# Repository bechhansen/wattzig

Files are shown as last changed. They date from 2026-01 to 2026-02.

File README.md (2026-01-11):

# WattZig - The Open Zigbee Power Meter









A Zigbee-based smart power meter reader for ESP32C6 that reads 3-phase electrical data via DLMS protocol and reports measurements to Zigbee hubs (Home Assistant, etc.).

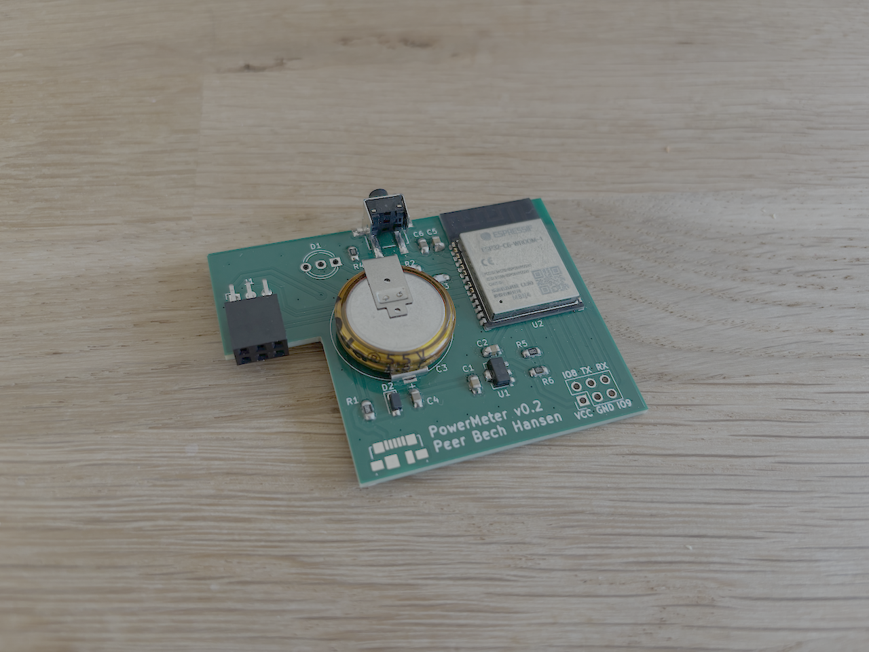
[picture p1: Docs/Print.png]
WattZig Hardware


## Overview

WattZig reads meter data via DLMS protocol over UART and reports 3-phase electrical measurements (voltage, current, active/reactive power, power factor, energy counters) through ZHA-compliant Zigbee clusters.

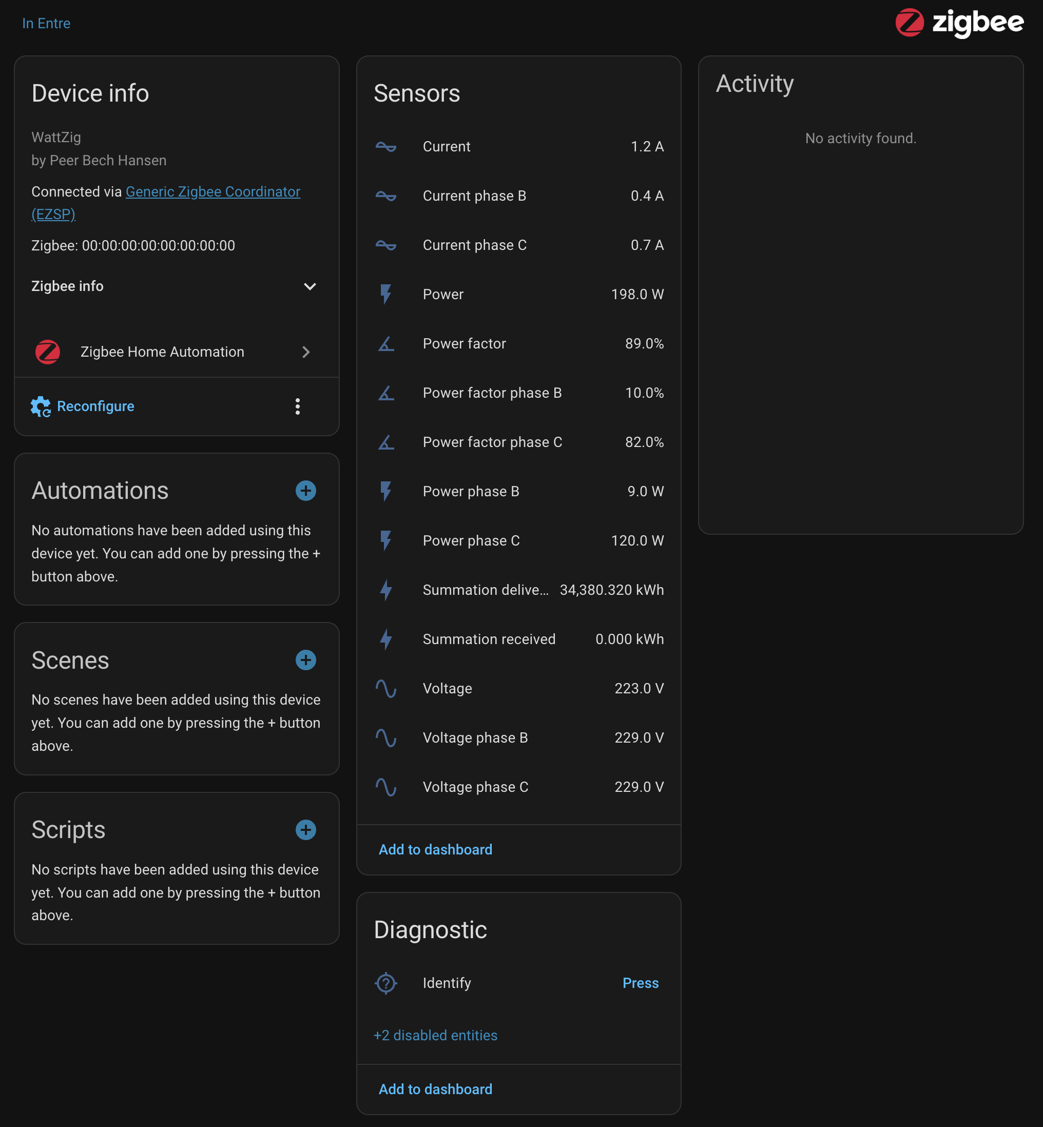
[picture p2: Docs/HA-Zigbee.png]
Zigbee Home Automation Interface


*The WattZig device reporting real-time electrical measurements to Home Assistant via Zigbee. All three phases show voltage (~228-230V), current (0.0-0.7A), power (9.0-130W), and power factor (11%-86%). The device also reports total energy consumption (34,351.77 kWh delivered) and can be integrated into automations and dashboards.*

## Features

- **3-Phase Metering**: Voltage, current, active/reactive power, power factor (phases A, B, C)
- **Energy Tracking**: Import/export energy counters with reporting
- **Zigbee ZHA**: Home Assistant integration via standard clusters
- **DLMS Parser**: State machine-based protocol handler at 2400 baud
- **Low Power**: FreeRTOS task design with Zigbee sleep support
- **Auto-Commissioning**: Network steering on first start
- **Status LEDs**: Green (data transmission), Red (commissioning)
- **Button Controls**: Long press (4s) = factory reset, double-click = restart

## Hardware Requirements

- **Microcontroller**: ESP32C6 (required for Zigbee)
- **ESP-IDF**: v5.5.2 (exact version)
- **Power Supply**: ≥4.5V input, MCP1700-3302E 3.3V regulator, 470µF–1000µF bulk capacitor (parallel to regulator)
- **UART1** (DLMS): TX=GPIO0, RX=GPIO1, 2400 baud, 8 bits, no parity
- **Peripherals**: GPIO5=Red LED, GPIO6=Green LED, GPIO4=Button

See [HARDWARE.md](HARDWARE.md) for complete Bill of Materials, schematics, and assembly instructions.

## Software Requirements

- **ESP-IDF v5.5.2**: `git clone -b v5.5.2 https://github.com/espressif/esp-idf.git && ./install.sh && source export.sh`
- **Dependencies** (auto-installed):
  - `espressif/esp-zigbee-lib` (~1.6.8)
  - `espressif/esp-zboss-lib` (~1.6.4)
  - `espressif/button` (2.4.1)

## Installation & Setup

1. **Clone and configure:**
   ```bash
   git clone <repo-url>
   cd wattzig/Software
   idf.py menuconfig
   ```

2. **Required menuconfig settings:**
   - `Component Config > Zigbee > Enable Zigbee Stack`
   - `Component Config > Zigbee > Device Type > End Device`
   - `Component Config > Power Management > Enable Power Management`

3. **Build and flash:**
   ```bash
   idf.py build
   idf.py -p /dev/ttyUSB0 -b 115200 flash
   idf.py -p /dev/ttyUSB0 monitor  # Exit: Ctrl+T then X
   ```

   See [FLASHING.md](FLASHING.md) for detailed hardware setup, boot mode configuration, and troubleshooting.

## Usage

**First Start:**
1. Device boots and performs factory reset
2. LED blinks (commissioning mode)
3. Device joins nearest Zigbee network via network steering
4. LED on briefly, then off
5. UART task starts reading meter data

**Normal Operation:**
- Device loads saved network config
- UART reads DLMS frames from meter
- Parsed data updates Zigbee cluster attributes
- Energy counters trigger ZCL reports

**Zigbee Endpoint 10:**
- Basic Cluster (0x0000): Device info
- Identify Cluster (0x0003): Identification
- Electrical Measurement (0x0B04): Voltage, current, power, power factor (all phases)
- Metering Cluster (0x0702): Energy delivered/received

## Configuration

Edit [Software/main/main.h](Software/main/main.h) for:
```c
#define ENDPOINT_ID 10                    // Zigbee endpoint
#define UART_NUM UART_NUM_1               // UART peripheral
#define UART_BAUD_RATE 2400               // Meter communication speed
#define LED_PIN 5                         // Red status LED
#define LED_PIN2 6                        // Green status LED
#define ED_AGING_TIMEOUT ESP_ZB_ED_AGING_TIMEOUT_64MIN
#define ED_KEEP_ALIVE 3000                // Keep-alive interval (ms)
```

## Debugging

### Enable Debug Logging
```c
// In app_main(), modify:
esp_log_level_set("Parser", ESP_LOG_DEBUG);  // Enable DLMS parser logs
esp_log_level_set("*", ESP_LOG_INFO);         // General logs
```

## References

- [ESP-IDF v5.5.2 Documentation](https://docs.espressif.com/projects/esp-idf/en/v5.5.2/)
- [Zigbee Cluster Library (ZCL)](https://zigbeealliance.org/)
- [Zigbee Cluster Library Specification](https://zigbeealliance.org/wp-content/uploads/2019/12/07-5123-06-zigbee-cluster-library-specification.pdf)
- [DLMS/COSEM Protocol](https://www.dlms.com/)
- [Home Assistant ZHA Integration](https://www.home-assistant.io/integrations/zha/)

## License

This project is licensed under the **GNU General Public License v3 (GPLv3)**.

You are free to use, modify, and distribute this software under the following conditions:
- Any derivative works must also be released under GPLv3
- You must provide access to the source code
- You must include this license and attribution
- You cannot create proprietary closed-source versions

See [LICENSE](LICENSE) for full details.

**GPLv3 ensures that improvements and modifications remain open source for the entire community.**

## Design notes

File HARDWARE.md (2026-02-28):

# WattZig Hardware - Bill of Materials (BOM)

## Summary
Complete electronic component list for WattZig ESP32C6-based Zigbee power meter reader.

## Microcontroller

| Qty | Part | Description | Notes | Ref |
|-----|---|---|---|-----|
| 1 | **ESP32-C6-WROOM-1** | 32-bit microcontroller with Zigbee/BLE | 2.4 GHz wireless, 160 MHz | U2 |

## Power Supply

| Qty | Part | Value | Package | Notes | Ref |
|-----|---|---|---|---|-----|
| 1 | **MCP1700-3302E** | 3.3V, 150mA LDO regulator | SOT-23-3 | Low dropout, stable 3.3V output | U1 |
| 1 | **Electrolytic Capacitor** | 470µF–1000µF, 6.3V+ | Through-hole or SMD | Prevents brownout| C? |
| 1 | **PHV-5R4H155-R** (PHV-5R4H474-R)| 1.5F, 5.4V | Through-hole | Supercapacitor for supplying suffiecent power to circuit | C3 |
| 2 | **Ceramic Capacitor** | 100nF (0.1µF) | 0603 SMD | Bypass capacitors (near VCC pins) |  |
| 1 | **Ceramic Capacitor** | 10µF | 0603 SMD | Additional smoothing |  |
| 1 | **1N5817W** | 450 mV @ 1 A | SOD-123 | Schottky Barrier Diode | D2 |

## I/O & Connectors

| Qty | Part | Description | Interface | Notes | Ref |
|-----|---|---|---|---|-----|
| 1 | **PPTC032LJBN-RC** | DLMS meter connection | 6POS (2X3) 2.54mm | https://www.digikey.at/en/products/detail/sullins-connector-solutions/PPTC032LJBN-RC/775975| J2 |
| 1 | **Programming Header** |  | 6-pin | For bootloader flashing | J1 |

## Status Indicators

| Qty | Part | Color | Package | GPIO | Function | Ref |
|-----|---|---|---|---|---|-----|
| 1 | **LED** | Red/Green |  | GPIO5 | Status indicator - commissioning | D1 |
| 2 | **Current Limiting Resistor** | 220Ω–330Ω | 1/4W or 0603 SMD | — | LED series resistors | |

## Control Interface

| Qty | Part | Type | Package | GPIO | Function | Url | Ref |
|-----|---|---|---|---|---|-----|-----|
| 1 | **Push Button** | Tactile switch, 12mm | 4-pin THT or SMD | GPIO4 | Long press (4s) = factory reset, double-click = restart | https://www.digikey.dk/da/products/detail/cit-relay-and-switch/CS1102V5-85F100/16607637 | SW1 |
| 1 | **Pull-up Resistor** | 10kΩ | 1/4W or 0603 SMD | — | Button debouncing |  | 

## Optional: Voltage Monitoring (Commented Code - WIP)

| Qty | Part | Value | Package | Notes | Ref |
|-----|---|---|---|---|-----|
| 2 | **Resistor** | 10kΩ | 1/4W or 0603 SMD | Voltage divider for VCC monitoring (ADC) |  |

### UART Pinout (Meter Connection)
```
Pin 1: GND
Pin 2: TX (GPIO0) - from ESP32 to meter (output)
Pin 3: RX (GPIO1) - from meter to ESP32 (input)
```
Baud rate: 2400, 8 bits, no parity, 1 stop bit

### GPIO Restrictions During Programming
- **GPIO8**: Must be HIGH during flash
- **GPIO9**: Must be LOW during flash
- These pins are not used in firmware

### LED Circuit
```
GPIO5 (Red LED)   ---|[220Ω]---|>|-----|GND
GPIO6 (Green LED) ---|[220Ω]---|>|-----|GND
```

### Button Circuit
```
GPIO4 ---|[10kΩ pull-up]---VCC
       |
       └──[Button]──GND
```

## Power Specifications

| Parameter | Value | Notes | Ref |
|---|---|---|-----|
| **Input voltage** | 4.5V–5.5V DC | Minimum 4.5V for regulator dropout | — |
| **Recommended input** | 5V @ 500mA minimum | Power supply capability | — |
| **Regulated output** | 3.3V @ 150mA | LDO regulator limit | U2 |
| **ESP32-C6 current** | ~80mA (active), ~20µA (sleep) | Idle load much lower | U1 |
| **Sleep mode** | ~10–50µA | With Zigbee sleep enabled | — |

## Supplier References (Example)

| Component | Example Part # | Supplier | Notes | Ref |
|---|---|---|---|-----|
| ESP32-C6-WROOM-1 | ESP32-C6-WROOM-1 | Digi-Key, Mouser | Check stock/lead times | U1 |
| MCP1700-3302E | MCP1700-3302E/CB | Digi-Key, Mouser | SOT-23 package | U2 |
| Bulk Capacitor | EKMG160ELL471MK20S | Digi-Key (Panasonic) | 470µF 10V electrolytic | C1 |
| LED Red | LTST-C150R | Digi-Key (Lite-On) | 3mm through-hole | LED1 |
| LED Green | LTST-C150G | Digi-Key (Lite-On) | 3mm through-hole | LED2 |
| Push Button | 9453 (Omron) | Digi-Key | 12mm tactile switch | SW1 |

## Revision History

| Version | Date | Changes |
|---|---|---|
| v10 | 2026-01-18 | Added Ref column to all BOM tables for component tracking |
| v9 | 2025-10-01 | Fixed supercapacitor placement (parallel, not series); confirmed bulk capacitor requirement |
| v8 | 2025-07-21 | Button moved to GPIO4; UART pins confirmed GPIO0/1 |
| v7 | 2025-06-10 | MCP1700-3302E selected; power circuit redesign |

## Cost Estimate (USD)

| Category | Est. Cost | Notes | Ref |
|---|---|---|-----|
| ESP32-C6-WROOM-1 | $3–5 | Module (prices vary by volume) | U1 |
| Regulator + Caps | $1–2 | MCP1700 + bulk cap + ceramics | U2, C1–C5 |
| LEDs + Resistors | $0.50 | Basic components | LED1, LED2, R1, R2 |
| Button + Resistor | $0.50 | Tactile switch | SW1, R3 |
| PCB | $2–5 | Prototype (Jlcpcb, Oshpark) | PCB1 |
| Connectors | $1–2 | JST headers, UART connector | J1–J3 |
| Enclosure | $1–3 | 3D printed resin or SLS | — |
| **Total** | **~$10–20** | Prototype quantities (1–10 units) | — |

## Next Steps for Assembly

1. Order PCB from Gerber files in `PCB/Out v0.1/`
2. Procure components from BOM above
3. Reflow solder (if SMD) or hand-solder THT components
4. **Critical check**: Verify bulk capacitor is parallel to regulator
5. Power test: Apply 5V, check 3.3V output with multimeter
6. Program ESP32-C6 via SPI/JTAG or UART bootloader
7. Assemble into 3D-printed enclosure (`3DPrint/WattZig v9.3mf`)

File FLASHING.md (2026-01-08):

# Firmware Upload Guide

This guide describes how to upload firmware to the PowerMeter ESP32C6 hardware using the service connector and standard flashing tools.

## Hardware Setup

### Service Connector Pinout

The PowerMeter hardware features a 6-pin service connector (2.54mm pitch) for programming and debugging:

| Pin | Signal | Purpose |
|-----|---|---|
| 1 | GND | Ground |
| 2 | VCC 3.3V | 3.3V Power Supply |
| 3 | TX | UART TX (GPIO1) |
| 4 | RX | UART RX (GPIO0) |
| 5 | GPIO8 | Boot Mode Control (High for Bootloader) |
| 6 | GPIO9 | Boot Mode Control (Low for Bootloader) |

### Required Hardware

1. **USB to UART Serial Adapter**: CP2102 STC or similar FTDI-based module
   - Must support 3.3V logic levels
   - Provides USB connectivity for flashing

2. **Test Rack PCB Clip**: 2.54mm pitch 6-pin clip connector
   - Connects to the service connector on the PowerMeter PCB
   - Allows quick connect/disconnect without soldering

3. **Cables**: Standard USB cable and connecting wires (typically included with serial adapter)

### Connection Diagram

Connect the USB to UART adapter to the service connector:

```
USB Adapter          Service Connector
───────────          ─────────────────
GND          ────→   GND (Pin 1)
5V/3.3V      ────→   VCC 3.3V (Pin 2)
TX (out)     ────→   RX (Pin 4)
RX (in)      ←────   TX (Pin 3)
GPIO/DTR/etc ────→   GPIO8 (Pin 5) - via pull-up or direct
GPIO/RTS/etc ────→   GPIO9 (Pin 6) - via pull-up or direct
```

**Important**: Ensure the USB adapter operates at 3.3V logic levels. Do not connect 5V directly to GPIO pins.

## Boot Mode Selection

To upload firmware, the ESP32C6 must be placed in bootloader mode.

### Boot Mode Requirements

For the ESP32C6 to enter bootloader mode:
- **GPIO8**: Must be pulled **HIGH** (typically connected to VCC 3.3V)
- **GPIO9**: Must be pulled **LOW** (typically connected to GND)

### Manual Boot Mode Entry

1. **Power off** the device
2. **Connect GPIO8 to VCC 3.3V** (high)
3. **Connect GPIO9 to GND** (low)
4. **Power on** the device
5. Device enters bootloader mode and is ready for flashing
6. After successful flashing, normal operation resumes automatically

###

## Flashing Firmware

### Prerequisites

1. Install esptool:
   ```bash
   pip install esptool
   ```

2. Confirm serial port availability:
   - **Linux/macOS**: `/dev/ttyUSB0` or `/dev/ttyUSB1` (or check with `ls /dev/tty*`)
   - **Windows**: `COM3`, `COM4`, etc. (check Device Manager)

### Standard Flashing Procedure

The standard way to flash firmware using esptool is:

#### Step 1: Download Firmware Binaries

Download the latest PowerMeter firmware release from GitHub:

1. Go to the [PowerMeter Releases](../../releases) page
2. Download the single release zip (e.g., `powermeter-v1.0.0-alpha.1.zip`) which contains:
   - `bootloader.bin` (bootloader)
   - `partition-table.bin` (partition table)
   - `firmware.bin` (application firmware)
3. Extract the zip to a local directory (e.g., `~/Downloads/powermeter-firmware/`)

#### Step 2: Put Device in Bootloader Mode

Manually connect GPIO8 (high) and GPIO9 (low) as described in [Boot Mode Selection](#boot-mode-selection).

#### Step 3: Flash Firmware

From the directory containing the downloaded .bin files:

```bash
esptool.py --chip esp32c6  --before default_reset --after hard_reset write_flash \
   --flash_size 4MB \
   0x0 bootloader.bin \
   0x8000 partition-table.bin \
   0x10000 firmware.bin

```

## Troubleshooting

### Device Not Found

- Confirm USB adapter is connected and recognized: `esptool.py version`
- Check port name: `esptool.py chip_id` (will list available ports)
- On Linux/macOS: May require `sudo` or udev rule configuration

### Connection Timeout During Flash

- Verify GPIO8 and GPIO9 are correctly set for bootloader mode
- Ensure 3.3V power is supplied during flashing
- Try lower baud rate: `-b 115200` instead of 460800

### CRC Error or Invalid Image

- Verify all three .bin files exist and are uncorrupted (check file sizes are reasonable, typically >100KB)
- Ensure you're in the correct directory containing bootloader.bin, partition-table.bin, and PowerMeter.bin
- Verify correct flash offsets: 0x0 (bootloader), 0x8000 (partition table), 0x20000 (application)
- Try erasing flash first (warning: clears all data):
  ```bash
  esptool.py -p /dev/ttyUSB0 erase_flash
  esptool.py -p /dev/ttyUSB0 -b 460800 --before default_reset --after hard_reset write_flash \
    --flash_mode dio --flash_freq 80m --flash_size keep \
    0x0 bootloader.bin 0x8000 partition-table.bin 0x20000 PowerMeter.bin
  ```

### Port Permission Denied (Linux)

Add user to dialout group:

```bash
sudo usermod -a -G dialout $USER
sudo reboot
```

Then unplug/replug USB adapter.

## Next Steps

After successful flashing:

1. Device boots automatically
2. LED blinks (commissioning mode)
3. Device joins the nearest Zigbee network
4. See [README.md](README.md) for normal operation details

## Building Firmware from Source

If you want to build firmware from source code instead of using pre-built binaries:

1. Clone the repository and navigate to `PowerMeter/Software`
2. Install [ESP-IDF v5.5.2](https://docs.espressif.com/projects/esp-idf/en/v5.5.2/esp32c6/get-started/index.html)
3. Run `idf.py menuconfig` to configure build options
4. Build with `idf.py build`
5. Flash using the steps above, replacing `bootloader.bin`, `partition-table.bin`, and `PowerMeter.bin` with paths in `build/bootloader/`, `build/partition_table/`, and `build/` respectively

## References

- [esptool.py Documentation](https://github.com/espressif/esptool)
- [Espressif Boot Mode Selection](https://docs.espressif.com/projects/esptool/en/latest/esp32c6/advanced-topics/boot-mode-selection.html)
- [ESP32C6 Datasheet](https://www.espressif.com/sites/default/files/documentation/esp32-c6_datasheet_en.pdf)

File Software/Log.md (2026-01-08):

2025-10-01
Code is running. For some reason it restarted because of brownout.
Monitoring only works just after flash. Maybe we need to set speed.

We need a bulk capacitor to prevent brownout

When searching for parts, look for:

"Electrolytic capacitor" - this is the capacitor type
Values: 470µF, 1000µF, or anywhere in between
Voltage rating: at least 6.3V (10V or 16V is common and fine)
Through-hole or SMD depending on your board

2025-07-21
When programming, GPIO8 needs to be high. GPIO9 needs to be low.
As we do not use GPIO8 for anything else we should be able to just set it to high.

Moved button pin from 7 to 4. It now works
TX and RX to 0 and 1. 

Programming works. Remember to disable logs.

Dual LED diode behaving strangely.

2025-06-10  
Found out my power circuit is wrong. I had the supercapacitor connected in series and not in parallel to the voltage regulator.
Also, the voltage regulator I'm using needs 4.5V because of a slight voltage drop. I need to use an MCP1700-3302E.

Use 10kΩ + 10kΩ voltage divider to read VCC voltage

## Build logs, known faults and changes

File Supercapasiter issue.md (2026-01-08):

# ESP32-C6 Zigbee Power Supply Issue - Documentation Summary

## Issue Description
ESP32-C6 brownout resets during Zigbee network initialization due to inadequate power delivery from supercapacitor with excessive ESR (Equivalent Series Resistance).

## Root Cause Analysis

### Current Hardware Configuration
- **Supercapacitor**: CE5R5105HF-ZJ (CDA Cap CE Series)
  - Capacitance: 1.0F
  - Voltage Rating: 5.5V
  - **ESR: 30Ω** ← PRIMARY PROBLEM
  - Height: 6.0mm
  - **Status**: Previously shorted, likely damaged (ESR may be higher than 30Ω)

- **Power Supply**: USB limited to 45mA average
- **LDO Regulator**: MCP1700T-3302E/MB (250mA max, 3.3V output)
- **Supply Voltage**: 4.1V at LDO input
- **Decoupling Network**: 470µF electrolytic (2cm from ESP32) + 10µF + 100nF ceramics

### Power Requirements
- **Zigbee TX Burst**: 100-150mA for milliseconds
- **Normal Operation**: ~30-50mA
- **Light Sleep**: ~1mA
- **Data Interval**: Every 10 seconds via UART

### Why 30Ω ESR Fails

**Voltage Drop Calculation:**
```
At 150mA Zigbee TX:
Voltage drop = 150mA × 30Ω = 4.5V

Available voltage = 4.1V - 4.5V = NEGATIVE (complete voltage collapse)
```

Even at 100mA:
```
Voltage drop = 100mA × 30Ω = 3.0V
Available voltage = 4.1V - 3.0V = 1.1V (insufficient for 3.3V LDO regulation)
```

The LDO requires minimum ~3.6V input to maintain 3.3V output. With 30Ω ESR, the voltage collapses below this threshold during Zigbee transmission, causing brownout resets.

## Solution Requirements

### Supercapacitor Specifications Needed
- **ESR**: <5Ω (preferably <3.5Ω)
- **Capacitance**: ≥0.47F (1.0F preferred)
- **Voltage Rating**: ≥5.5V
- **Height**: ≤10mm (ideally ≤13mm if flexibility possible)
- **Status**: Undamaged (never shorted)

### Recommended Supercapacitor Options

#### Option 1: KEMET FT Series (BEST PERFORMANCE)
**Part Number**: FT0H105ZF
- Capacitance: 1.0F
- **ESR: 3.5Ω** ✓ (8.5× better than current)
- Voltage: 5.5V
- Height: **13.0mm** (3mm over target)
- Max Current (30 min): 1.5mA

**Voltage drop at 150mA**: 150mA × 3.5Ω = **525mV** (acceptable)
**Available voltage**: 4.1V - 0.525V = **3.575V** ✓ (sufficient for LDO)

**Trade-off**: Exceeds height constraint by 3mm but provides excellent performance.

#### Option 2: Alternative Search Required
No supercapacitors found that meet BOTH <10mm height AND <5Ω ESR requirements. This is a fundamental physics limitation - low ESR requires larger electrode surface area.

### Alternative Power Solutions

#### LiPo Battery (RECOMMENDED IF HEIGHT CRITICAL)
- **Voltage**: 3.7V, 150-250mAh
- **ESR**: <0.1Ω (35× better than FT0H105ZF, 300× better than current)
- **Thickness**: 4-6mm ✓
- **Requires**: Charge management IC (e.g., MCP73831)
- **Advantages**: 
  - Ideal for pulse current applications
  - Fits height constraint
  - Much lower ESR
  - Designed for exactly this use case

## Working Solution: Light Sleep Mode

### Implementation Strategy
Given 10-second data intervals, implement light sleep with UART wake-up:
```c
// Power consumption in light sleep: ~1mA
// Voltage drop: 1mA × 30Ω = 30mV (acceptable)
// Recharge time: 9.9 seconds per cycle (sufficient)

esp_sleep_enable_uart_wakeup(UART_NUM);
esp_light_sleep_start();
```

### Additional Optimizations Required

1. **Reduce Zigbee TX Power**
```c
   esp_zb_set_tx_power(0);  // 0 dBm instead of maximum
   // Further reduction: -3 dBm or -6 dBm if range permits
```

2. **Lower CPU Frequency**
```c
   esp_pm_config_t pm_config = {
       .max_freq_mhz = 80,  // Reduce from 160MHz
       .min_freq_mhz = 40,
       .light_sleep_enable = true
   };
```

3. **Move 470µF Bulk Capacitor Closer**
   - **Current**: 2cm from ESP32-C6
   - **Target**: <5mm from ESP32-C6 power pins
   - Reduces trace inductance and resistance

4. **Verify Decoupling Network Integrity**
   - 470µF electrolytic on 3.3V rail
   - 10µF ceramic at ESP32-C6
   - 100nF ceramic at ESP32-C6 power pins (<5mm)

## Critical Issue: Zigbee Pairing

### Pairing Power Requirements
- **Duration**: 10-30+ seconds continuous
- **Current**: 80-150mA sustained (not just bursts)
- **Total Energy**: ~10 Watt-seconds

### Why Current Supercap CANNOT Handle Pairing
```
Sustained 100mA for 30 seconds:
Voltage drop = 100mA × 30Ω = 3V
Available voltage = 4.1V - 3V = 1.1V ← INSUFFICIENT

Energy stored in 1F @ 4.1V = 8.4 joules
Energy needed for pairing = ~10 joules
Result: Supercap fully discharges, system crashes
```

### Pairing Solution Options

**Option A: External Power During Pairing (RECOMMENDED)**
- Use unrestricted USB power supply during initial pairing
- After pairing complete, switch to 45mA-limited supply
- Network credentials stored in flash, device rejoins automatically

**Option B: Bypass Jumper**
- Add physical jumper that bypasses current limit during pairing
- Remove after pairing complete
- Document in user manual

**Option C: Field Pairing Procedure**
- Provide external power supply for re-pairing scenarios
- Or implement "pairing mode" button that requires external power

### Normal Rejoin vs. Initial Pairing
- **Rejoining** (after power cycle): 1-5 seconds, stored credentials
- **Initial pairing**: 10-30+ seconds, full network discovery
- Supercap may handle rejoin, but NOT initial pairing

## Recommended Action Plan

### Immediate Actions (Software Fixes)
1. ✅ Implement light sleep with UART wake-up
2. ✅ Reduce Zigbee TX power to 0 dBm or lower
3. ✅ Set CPU frequency to 80MHz
4. ✅ Move 470µF capacitor closer to ESP32-C6
5. ✅ Use external power for initial Zigbee pairing

### Hardware Upgrade Options

#### Option 1: Accept 13mm Height Limit
- **Replace with**: KEMET FT0H105ZF
- **ESR**: 3.5Ω (excellent performance)
- **Height**: 13mm (3mm over budget)
- **Result**: Reliable operation with proper power margin

#### Option 2: Redesign with LiPo Battery
- **Battery**: 3.7V 150-250mAh
- **Add**: MCP73831 charge controller
- **ESR**: <0.1Ω (best performance)
- **Height**: 4-6mm ✓
- **Result**: Ideal solution for pulse current applications

#### Option 3: Continue with Current Hardware
- Implement all software optimizations above
- Test if light sleep + reduced TX power eliminates brownouts
- Accept that initial pairing requires external power
- **Risk**: May still experience intermittent brownouts during TX

## Technical Background

### ESR (Equivalent Series Resistance)
Internal resistance of capacitor that causes voltage drop when current flows through it.
- **Formula**: V_drop = Current × ESR
- **Impact**: Higher ESR = greater voltage collapse under load
- **Physics**: Low ESR requires larger electrode surface area (more physical volume)

### Why This Matters for Zigbee
Zigbee transmission creates brief high-current pulses (100-150mA). With high ESR, these pulses cause instantaneous voltage drops that trigger brownout protection, resetting the system.

## Conclusion

The CE5R5105HF-ZJ supercapacitor with 30Ω ESR is fundamentally unsuitable for ESP32-C6 Zigbee applications requiring 100-150mA transmission bursts. The primary issue is excessive ESR causing voltage collapse, not insufficient capacitance.

**Best long-term solution**: Replace with KEMET FT0H105ZF (3.5Ω ESR) if 13mm height is acceptable, or redesign with LiPo battery for optimal performance within height constraint.

**Interim solution**: Implement light sleep mode with reduced TX power and optimized hardware placement. This may provide acceptable operation for the 10-second data interval use case, but initial Zigbee pairing will still require external power.

---

**Document Date**: 2024
**Hardware**: ESP32-C6, CE5R5105HF-ZJ supercapacitor, MCP1700 LDO
**Application**: Zigbee end device with 10-second UART data intervals

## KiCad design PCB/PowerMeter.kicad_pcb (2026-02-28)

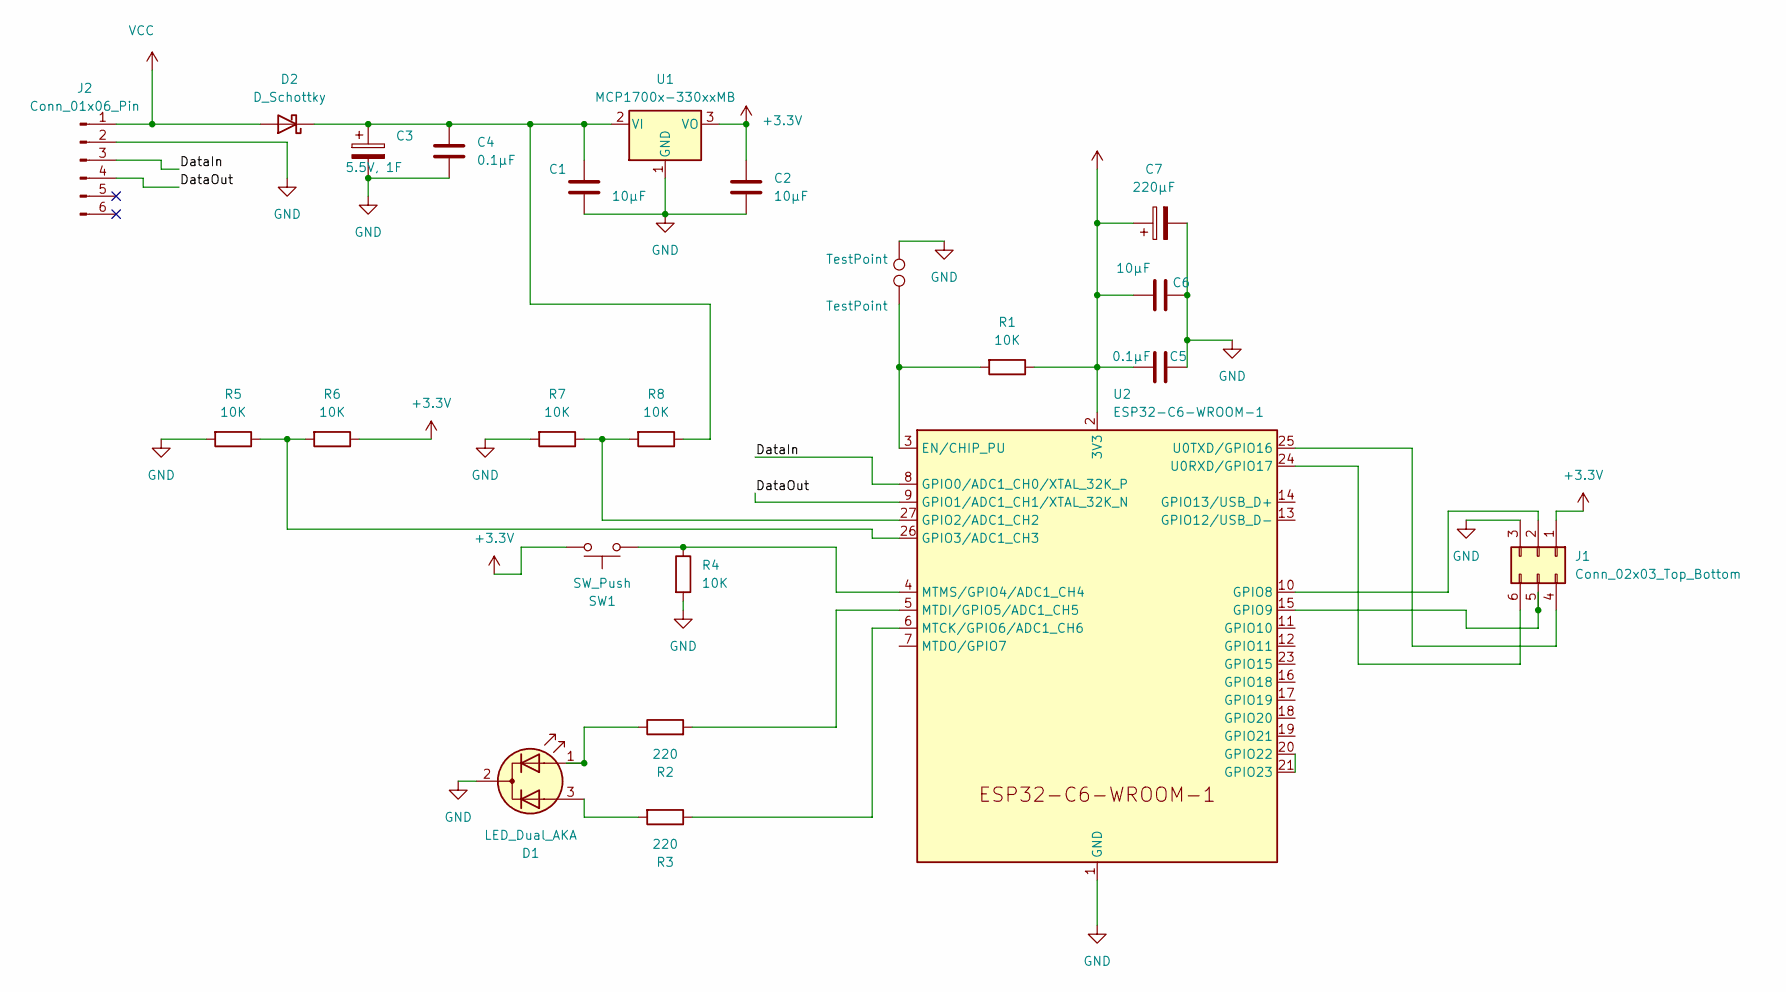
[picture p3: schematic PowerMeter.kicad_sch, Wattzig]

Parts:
C1, C2, C6: 10μF; C_0805_2012Metric_Pad1.18x1.45mm_HandSolder
C3: 5.5V, 1F; PHV-5R4H155-R
C4, C5: 0.1μF; C_0805_2012Metric_Pad1.18x1.45mm_HandSolder
C7: 220µF; C_1812_4532Metric
D1: LED_Dual_AKA; LED_D5.0mm-3
D2: D_Schottky; Nexperia_CFP3_SOD-123W
J1: Conn_02x03_Top_Bottom; PinHeader_2x03_P2.54mm_Vertical
J2: Conn_01x06_Pin; PinSocket_2x03_P2.54mm_Horizontal
R1, R4, R5, R6, R7, R8: 10K; R_0805_2012Metric_Pad1.20x1.40mm_HandSolder
R2, R3: 220; R_0805_2012Metric_Pad1.20x1.40mm_HandSolder
RST1, RST2: TestPoint; TestPoint_Pad_D2.0mm
SW1: SW_Push; CS1102V1135F160_pbh
U1: MCP1700x-330xxMB; SOT-89-3
U2: ESP32-C6-WROOM-1

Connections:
+3.3V: C2.1, C5.1, C6.1, C7.1, J1.1, R1.1, R6.1, SW1.1, U1.3 (VO), U2.2 (3V3)
/DataIn: J2.3, U2.8 (GPIO0/ADC1_CH0/XTAL_32K_P)
/DataOut: J2.4, U2.9 (GPIO1/ADC1_CH1/XTAL_32K_N)
GND: C1.2, C2.2, C3.2, C4.2, C5.2, C6.2, C7.2, D1.2 (K), J1.3, J2.2, R4.2, R5.2, R7.2, RST1.1, U1.1 (GND), U2.1 (GND), U2.28 (GND), U2.29 (GND)
unnamed: D1.1 (A1), R2.1
unnamed: D1.3 (A2), R3.2
unnamed: C1.1, C3.1, C4.1, D2.1 (K), R8.1, U1.2 (VI)
unnamed: J1.2, U2.10 (GPIO8)
unnamed: J1.4, U2.25 (U0TXD/GPIO16)
unnamed: J1.5, U2.15 (GPIO9)
unnamed: J1.6, U2.24 (U0RXD/GPIO17)
unnamed: R1.2, RST2.1, U2.3 (EN/CHIP_PU)
unnamed: R7.1, R8.2, U2.27 (GPIO2/ADC1_CH2)
unnamed: R5.1, R6.2, U2.26 (GPIO3/ADC1_CH3)
unnamed: U2.20 (GPIO22), U2.21 (GPIO23)
unnamed: R3.1, U2.6 (MTCK/GPIO6/ADC1_CH6)
unnamed: R2.2, U2.5 (MTDI/GPIO5/ADC1_CH5)
unnamed: R4.1, SW1.2, U2.4 (MTMS/GPIO4/ADC1_CH4)
VCC: D2.2 (A), J2.1

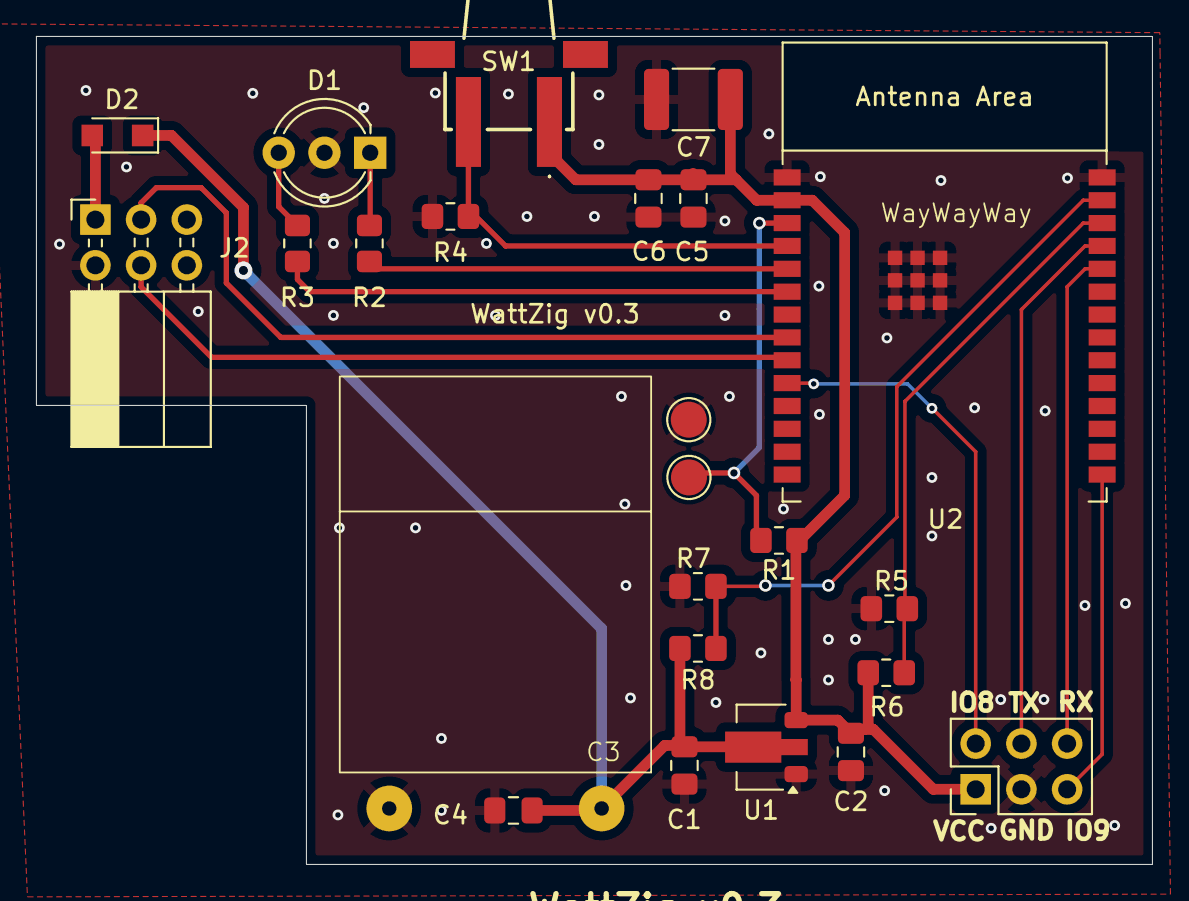
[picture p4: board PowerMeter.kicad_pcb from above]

Board: 2 copper layers, 62.0 x 46.0 mm, 24 parts (0 on the bottom side), 19 nets.

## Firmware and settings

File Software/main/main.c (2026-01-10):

#include "esp_check.h"
#include "esp_log.h"
#include "nvs_flash.h"
#include "freertos/FreeRTOS.h"
#include "freertos/task.h"
#include "ha/esp_zigbee_ha_standard.h"
#include "main.h"
#include "driver/uart.h"
#include "kamstrup_test_data.h"
#include <esp_app_desc.h>

#include "esp_random.h"
#include "dlms_parser.h"

#include "esp_timer.h"
#include "esp_zigbee_attribute.h"

#include <stdio.h>
#include <stdint.h>
#include <time.h>
#include <inttypes.h>
#include <string.h>

#include "driver/gpio.h"
#include <iot_button.h>

#include "esp_pm.h"
#include "esp_err.h"

#include "esp_adc/adc_oneshot.h"
#include "esp_adc/adc_cali.h"
#include "esp_adc/adc_cali_scheme.h"

#ifdef CONFIG_PM_ENABLE
#include "esp_pm.h"
#include "esp_private/esp_clk.h"
#include "esp_sleep.h"
#endif

#if !defined ZB_ED_ROLE
#error Define ZB_ED_ROLE in idf.py menuconfig to compile light (End Device) source code.
#endif

#if DATA_SIMULATION
#include "kamstrup_test_data.h"
#endif

static const char *TAG = "WattZig";

static QueueHandle_t uart_queue;
static dlms_parser_t parser;
static int64_t lastReceived = 0;
static bool waitingForSilence = true;
static TaskHandle_t task_handle = NULL;

// static int adc_raw[2][10];
// static int voltage[2][10];

// uint32_t convert_timestamp_to_seconds_since_2000(const char* timestamp) {
//     // Parse timestamp parts
//     int year, month, day, hour, minute, second;
//     sscanf(timestamp, "%4X%2X%2X%2X%2X%2X", &year, &month, &day, &hour, &minute, &second);

//     // Create tm structure for the timestamp
//     struct tm timestamp_tm = {0};
//     timestamp_tm.tm_year = year - 1900;  // tm_year is years since 1900
//     timestamp_tm.tm_mon = month - 1;     // tm_mon is 0-11
//     timestamp_tm.tm_mday = day;
//     timestamp_tm.tm_hour = hour;
//     timestamp_tm.tm_min = minute;
//     timestamp_tm.tm_sec = second;

//     // Create tm structure for Jan 1, 2000
//     struct tm epoch_2000_tm = {0};
//     epoch_2000_tm.tm_year = 100;  // 2000 - 1900
//     epoch_2000_tm.tm_mday = 1;    // 1st day of month

//     // Convert both to time_t (seconds since Jan 1, 1970)
//     time_t timestamp_time = mktime(&timestamp_tm);
//     time_t epoch_2000_time = mktime(&epoch_2000_tm);

//     // Account for timezone differences as mktime uses local time
//     // Adjust for GMT/UTC if necessary based on your system

//     // Calculate difference
//     uint32_t seconds_since_2000 = (uint32_t)(timestamp_time - epoch_2000_time);

//     return seconds_since_2000;
// }

int8_t convert_to_int8(uint8_t *bytes)
{
    return (int8_t)(bytes[0]);
}

uint16_t convert_to_uint16(uint8_t *bytes)
{
    return (uint16_t)(bytes[0] << 8 | bytes[1]);
}

int16_t convert_to_int16(uint8_t *bytes)
{
    return (int16_t)(bytes[0] << 8 | bytes[1]);
}

uint32_t convert_to_uint32(uint8_t *bytes)
{
    return (uint32_t)(bytes[0] << 24 | bytes[1] << 16 | bytes[2] << 8 | bytes[3]);
}

static void handle_dlms_field(dlms_field_t *field)
{

    if (field == NULL)
    {
        ESP_LOGW(TAG, "Received null field");
        return;
    }

    switch (field->type)
    {

    case START:
        ESP_LOGI(TAG, "Start received. Acquiring lock");
        esp_zb_lock_acquire(portMAX_DELAY);
        gpio_set_level(LED_PIN, 0);
        gpio_set_level(LED_PIN2, 1); // Green LED on
        break;

    case END:
        ESP_LOGI(TAG, "End received. Releasing lock");
        esp_zb_lock_release();
        gpio_set_level(LED_PIN, 0);
        gpio_set_level(LED_PIN2, 0);
        break;

    case RMS_VOLTAGE_A:
        uint16_t valueA = convert_to_uint16(field->data);
        ESP_LOGI(TAG, "Received RMS Voltage A: %d", valueA);
        esp_zb_zcl_set_attribute_val(ENDPOINT_ID, ESP_ZB_ZCL_CLUSTER_ID_ELECTRICAL_MEASUREMENT, ESP_ZB_ZCL_CLUSTER_SERVER_ROLE, ESP_ZB_ZCL_ATTR_ELECTRICAL_MEASUREMENT_RMSVOLTAGE_ID, &valueA, false); //!< Represents the most recent RMS voltage reading in @e Volts (V).
        break;

    case RMS_VOLTAGE_B:
        uint16_t valueB = convert_to_uint16(field->data);
        ESP_LOGI(TAG, "Received RMS Voltage B: %d", valueB);
        esp_zb_zcl_set_attribute_val(ENDPOINT_ID, ESP_ZB_ZCL_CLUSTER_ID_ELECTRICAL_MEASUREMENT, ESP_ZB_ZCL_CLUSTER_SERVER_ROLE, ESP_ZB_ZCL_ATTR_ELECTRICAL_MEASUREMENT_RMSVOLTAGE_PHB_ID, &valueB, false); //!< Represents the most recent RMS voltage reading in @e Volts (V).
        break;

    case RMS_VOLTAGE_C:
        uint16_t valueC = convert_to_uint16(field->data);
        ESP_LOGI(TAG, "Received RMS Voltage C: %d", valueC);
        esp_zb_zcl_set_attribute_val(ENDPOINT_ID, ESP_ZB_ZCL_CLUSTER_ID_ELECTRICAL_MEASUREMENT, ESP_ZB_ZCL_CLUSTER_SERVER_ROLE, ESP_ZB_ZCL_ATTR_ELECTRICAL_MEASUREMENT_RMSVOLTAGE_PHC_ID, &valueC, false); //!< Represents the most recent RMS voltage reading in @e Volts (V).
        break;

    case POWER_FACTOR_A:
        uint16_t factorA = convert_to_uint16(field->data);
        uint8_t factorA_8 = (uint8_t)(factorA);
        ESP_LOGI(TAG, "Received factor A: %d", factorA);
        esp_zb_zcl_set_attribute_val(ENDPOINT_ID, ESP_ZB_ZCL_CLUSTER_ID_ELECTRICAL_MEASUREMENT, ESP_ZB_ZCL_CLUSTER_SERVER_ROLE, ESP_ZB_ZCL_ATTR_ELECTRICAL_MEASUREMENT_POWER_FACTOR_ID, &factorA_8, false);
        break;

    case POWER_FACTOR_B:
        uint16_t factorB = convert_to_uint16(field->data);
        uint8_t factorB_8 = (uint8_t)(factorB);
        ESP_LOGI(TAG, "Received factor B: %d", factorB);
        esp_zb_zcl_set_attribute_val(ENDPOINT_ID, ESP_ZB_ZCL_CLUSTER_ID_ELECTRICAL_MEASUREMENT, ESP_ZB_ZCL_CLUSTER_SERVER_ROLE, ESP_ZB_ZCL_ATTR_ELECTRICAL_MEASUREMENT_POWER_FACTOR_PH_B_ID, &factorB_8, false);
        break;

    case POWER_FACTOR_C:
        uint16_t factorC = convert_to_uint16(field->data);
        uint8_t factorC_8 = (uint8_t)(factorC);
        ESP_LOGI(TAG, "Received factor C: %d", factorC);
        esp_zb_zcl_set_attribute_val(ENDPOINT_ID, ESP_ZB_ZCL_CLUSTER_ID_ELECTRICAL_MEASUREMENT, ESP_ZB_ZCL_CLUSTER_SERVER_ROLE, ESP_ZB_ZCL_ATTR_ELECTRICAL_MEASUREMENT_POWER_FACTOR_PH_C_ID, &factorC_8, false);
        break;

    case RMS_CURRENT_A:
        uint32_t currentA = convert_to_uint32(field->data);
        uint16_t currentA_16 = (uint16_t)(currentA);
        ESP_LOGI(TAG, "Received RMS current A: %u", currentA);
        esp_zb_zcl_set_attribute_val(ENDPOINT_ID, ESP_ZB_ZCL_CLUSTER_ID_ELECTRICAL_MEASUREMENT, ESP_ZB_ZCL_CLUSTER_SERVER_ROLE, ESP_ZB_ZCL_ATTR_ELECTRICAL_MEASUREMENT_RMSCURRENT_ID, &currentA_16, false);
        break;

    case RMS_CURRENT_B:
        uint32_t currentB = convert_to_uint32(field->data);
        uint16_t currentB_16 = (uint16_t)(currentB);
        ESP_LOGI(TAG, "Received RMS current B: %u", currentB);
        esp_zb_zcl_set_attribute_val(ENDPOINT_ID, ESP_ZB_ZCL_CLUSTER_ID_ELECTRICAL_MEASUREMENT, ESP_ZB_ZCL_CLUSTER_SERVER_ROLE, ESP_ZB_ZCL_ATTR_ELECTRICAL_MEASUREMENT_RMSCURRENT_PHB_ID, &currentB_16, false);
        break;

    case RMS_CURRENT_C:
        uint32_t currentC = convert_to_uint32(field->data);
        uint16_t currentC_16 = (uint16_t)(currentC);
        ESP_LOGI(TAG, "Received RMS current C: %u", currentC);
        esp_zb_zcl_set_attribute_val(ENDPOINT_ID, ESP_ZB_ZCL_CLUSTER_ID_ELECTRICAL_MEASUREMENT, ESP_ZB_ZCL_CLUSTER_SERVER_ROLE, ESP_ZB_ZCL_ATTR_ELECTRICAL_MEASUREMENT_RMSCURRENT_PHC_ID, &currentC_16, false);
        break;

    case ACTIVE_POWER_A:
        uint32_t powerA = convert_to_uint32(field->data);
        int16_t powerA_16 = (int16_t)(powerA);
        ESP_LOGI(TAG, "Received ACTIVE_POWER_A: %u", powerA);
        esp_zb_zcl_set_attribute_val(ENDPOINT_ID, ESP_ZB_ZCL_CLUSTER_ID_ELECTRICAL_MEASUREMENT, ESP_ZB_ZCL_CLUSTER_SERVER_ROLE, ESP_ZB_ZCL_ATTR_ELECTRICAL_MEASUREMENT_ACTIVE_POWER_ID, &powerA_16, false);
        break;

    case ACTIVE_POWER_B:
        uint32_t powerB = convert_to_uint32(field->data);
        int16_t powerB_16 = (int16_t)(powerB);
        ESP_LOGI(TAG, "Received ACTIVE_POWER_B: %u", powerB);
        esp_zb_zcl_set_attribute_val(ENDPOINT_ID, ESP_ZB_ZCL_CLUSTER_ID_ELECTRICAL_MEASUREMENT, ESP_ZB_ZCL_CLUSTER_SERVER_ROLE, ESP_ZB_ZCL_ATTR_ELECTRICAL_MEASUREMENT_ACTIVE_POWER_PHB_ID, &powerB_16, false);
        break;

    case ACTIVE_POWER_C:
        uint32_t powerC = convert_to_uint32(field->data);
        int16_t powerC_16 = (int16_t)(powerC);
        ESP_LOGI(TAG, "Received ACTIVE_POWER_C: %u", powerC);
        esp_zb_zcl_set_attribute_val(ENDPOINT_ID, ESP_ZB_ZCL_CLUSTER_ID_ELECTRICAL_MEASUREMENT, ESP_ZB_ZCL_CLUSTER_SERVER_ROLE, ESP_ZB_ZCL_ATTR_ELECTRICAL_MEASUREMENT_ACTIVE_POWER_PHC_ID, &powerC_16, false);
        break;

    case REACTIVE_POWER_A:
        uint32_t rePowerA = convert_to_uint32(field->data);
        int16_t rePowerA_16 = (int16_t)(rePowerA);
        // ESP_LOGI(TAG, "Received REACTIVE A: %u", rePowerA);
        esp_zb_zcl_set_attribute_val(ENDPOINT_ID, ESP_ZB_ZCL_CLUSTER_ID_ELECTRICAL_MEASUREMENT, ESP_ZB_ZCL_CLUSTER_SERVER_ROLE, ESP_ZB_ZCL_ATTR_ELECTRICAL_MEASUREMENT_REACTIVE_POWER_ID, &rePowerA_16, false);
        break;

    case REACTIVE_POWER_B:
        uint32_t rePowerB = convert_to_uint32(field->data);
        int16_t rePowerB_16 = (int16_t)(rePowerB);
        // ESP_LOGI(TAG, "Received REACTIVE B: %u", rePowerB);
        esp_zb_zcl_set_attribute_val(ENDPOINT_ID, ESP_ZB_ZCL_CLUSTER_ID_ELECTRICAL_MEASUREMENT, ESP_ZB_ZCL_CLUSTER_SERVER_ROLE, ESP_ZB_ZCL_ATTR_ELECTRICAL_MEASUREMENT_REACTIVE_POWER_PH_B_ID, &rePowerB_16, false);
        break;

    case REACTIVE_POWER_C:
        uint32_t rePowerC = convert_to_uint32(field->data);
        int16_t rePowerC_16 = (int16_t)(rePowerC);
        // ESP_LOGI(TAG, "Received REACTIVE C: %u", rePowerC);
        esp_zb_zcl_set_attribute_val(ENDPOINT_ID, ESP_ZB_ZCL_CLUSTER_ID_ELECTRICAL_MEASUREMENT, ESP_ZB_ZCL_CLUSTER_SERVER_ROLE, ESP_ZB_ZCL_ATTR_ELECTRICAL_MEASUREMENT_REACTIVE_POWER_PH_C_ID, &rePowerC_16, false);
        break;

    case ACTIVE_ENERGY_IMPORT:
        uint64_t powerImport = convert_to_uint32(field->data);
        ESP_LOGI(TAG, "Received ACTIVE_ENERGY_IMPORT: %" PRIu64, powerImport);

        esp_zb_zcl_set_attribute_val(ENDPOINT_ID, ESP_ZB_ZCL_CLUSTER_ID_METERING, ESP_ZB_ZCL_CLUSTER_SERVER_ROLE, ESP_ZB_ZCL_ATTR_METERING_CURRENT_SUMMATION_DELIVERED_ID, &powerImport, false);

        esp_zb_zcl_report_attr_cmd_t report_attr_cmd = {0};
        report_attr_cmd.address_mode = ESP_ZB_APS_ADDR_MODE_DST_ADDR_ENDP_NOT_PRESENT;
        report_attr_cmd.attributeID = ESP_ZB_ZCL_ATTR_METERING_CURRENT_SUMMATION_DELIVERED_ID;
        report_attr_cmd.direction = ESP_ZB_ZCL_CMD_DIRECTION_TO_CLI;
        report_attr_cmd.clusterID = ESP_ZB_ZCL_CLUSTER_ID_METERING;
        // report_attr_cmd.cluster_role = ESP_ZB_ZCL_CLUSTER_SERVER_ROLE;
        report_attr_cmd.zcl_basic_cmd.src_endpoint = ENDPOINT_ID;

        esp_zb_zcl_report_attr_cmd_req(&report_attr_cmd);

        break;

    case ACTIVE_ENERGY_EXPORT:
        uint64_t powerExport = convert_to_uint32(field->data);
        ESP_LOGI(TAG, "Received ACTIVE_ENERGY_EXPORT: %" PRIu64, powerExport);

        esp_zb_zcl_set_attribute_val(ENDPOINT_ID, ESP_ZB_ZCL_CLUSTER_ID_METERING, ESP_ZB_ZCL_CLUSTER_SERVER_ROLE, ESP_ZB_ZCL_ATTR_METERING_CURRENT_SUMMATION_RECEIVED_ID, &powerExport, false);

        esp_zb_zcl_report_attr_cmd_t report_attr_cmd_export = {0};
        report_attr_cmd_export.address_mode = ESP_ZB_APS_ADDR_MODE_DST_ADDR_ENDP_NOT_PRESENT;
        report_attr_cmd_export.attributeID = ESP_ZB_ZCL_ATTR_METERING_CURRENT_SUMMATION_RECEIVED_ID;
        report_attr_cmd_export.direction = ESP_ZB_ZCL_CMD_DIRECTION_TO_CLI;
        report_attr_cmd_export.clusterID = ESP_ZB_ZCL_CLUSTER_ID_METERING;
        // report_attr_cmd.cluster_role = ESP_ZB_ZCL_CLUSTER_SERVER_ROLE;
        report_attr_cmd_export.zcl_basic_cmd.src_endpoint = ENDPOINT_ID;

        esp_zb_zcl_report_attr_cmd_req(&report_attr_cmd_export);

        break;

    case DLMS_FIELD_TIMESTAMP:
        ESP_LOGI(TAG, "Received timestamp");

        ESP_LOGI(TAG, "Timestamp: %s", (const char *)field->data);

        // uint32_t timestamp = convert_timestamp_to_seconds_since_2000((const char *)field->data);
        // ESP_LOGI(TAG, "Timestamp: %u", timestamp);
        break;

    case SERIAL_NUMBER:
        uint32_t serial = (field->data[0] << 24) |
                          (field->data[1] << 16) |
                          (field->data[2] << 8) |
                          field->data[3];

        ESP_LOGI(TAG, "Serial Number: %u", serial);

        esp_zb_zcl_attr_t *attr = esp_zb_zcl_get_attribute(ENDPOINT_ID, ESP_ZB_ZCL_CLUSTER_ID_METERING, ESP_ZB_ZCL_CLUSTER_SERVER_ROLE, ESP_ZB_ZCL_ATTR_METERING_METER_SERIAL_NUMBER_ID);
        bool should_set = true;
        if (attr && attr->data_p != NULL)
        {
            uint8_t *cur = (uint8_t *)attr->data_p;
            if (cur[0] != 0)
            {
                ESP_LOGI(TAG, "Meter serial already set, skipping update");
                should_set = false;
            }
        }

        if (should_set)
        {
            uint8_t serial_octstr[5] = {
                4, // Length byte
                field->data[0],
                field->data[1],
                field->data[2],
                field->data[3]};

            esp_zb_zcl_set_attribute_val(ENDPOINT_ID, ESP_ZB_ZCL_CLUSTER_ID_METERING, ESP_ZB_ZCL_CLUSTER_SERVER_ROLE, ESP_ZB_ZCL_ATTR_METERING_METER_SERIAL_NUMBER_ID, &serial_octstr, false);
            ESP_LOGI(TAG, "Meter serial attribute set");
        }
        break;

    default:
        break;
    }
}

static void initLedFlash(void *pvParameters)
{
    gpio_set_level(LED_PIN, 0);
    gpio_set_level(LED_PIN2, 0);

    bool on = false;
    while (1)
    {
        if (on)
        {
            gpio_set_level(LED_PIN, 1);
            vTaskDelay(50 / portTICK_PERIOD_MS);
        }
        else
        {
            gpio_set_level(LED_PIN, 0);
            vTaskDelay(1000 / portTICK_PERIOD_MS);
        }

        on = !on;
    }
}

static void uart_event_task(void *pvParameters)
{

    lastReceived = esp_timer_get_time();

    uart_event_t event;
    uint8_t *data = (uint8_t *)malloc(UART_RX_BUFFER_SIZE);

    while (1)
    {
        if (xQueueReceive(uart_queue, (void *)&event, portMAX_DELAY))
        {
            switch (event.type)
            {
            case UART_DATA:

                // Read the received data
                int length = uart_read_bytes(UART_NUM, data, event.size, portMAX_DELAY);
                if (length > 0)
                {

                    int64_t currentTime = esp_timer_get_time();

                    if (waitingForSilence && (currentTime - lastReceived) < 3000000)
                    {
                        ESP_LOGI(TAG, "Waiting for silence...");
                        lastReceived = currentTime;
                        continue;
                    }

                    waitingForSilence = false;

                    for (int i = 0; i < length; i++)
                    {
                        if (!dlms_parser_process_byte(&parser, data[i]))
                        {
                            ESP_LOGW(TAG, "Parser error at byte %d", i);
                            dlms_parser_init(&parser);
                        }
                    }
                }
                break;
            case UART_FIFO_OVF:
                ESP_LOGW(TAG, "UART FIFO Overflow");
                uart_flush_input(UART_NUM);
                xQueueReset(uart_queue);
                break;
            case UART_BUFFER_FULL:
                ESP_LOGW(TAG, "UART Ring Buffer Full");
                uart_flush_input(UART_NUM);
                xQueueReset(uart_queue);
                break;
            case UART_BREAK:
                ESP_LOGW(TAG, "UART Break");
                break;
            case UART_PARITY_ERR:
                ESP_LOGW(TAG, "UART Parity Error");
                break;
            case UART_FRAME_ERR:
                ESP_LOGW(TAG, "UART Frame Error");
                break;
            default:
                break;
            }
        }
    }
    free(data);
}

// Initialize UART
void uart_init(void)
{
    uart_config_t uart_config = {
        .baud_rate = UART_BAUD_RATE,
        .data_bits = UART_DATA_8_BITS,
        .parity = UART_PARITY_DISABLE,
        .stop_bits = UART_STOP_BITS_1,
        .flow_ctrl = UART_HW_FLOWCTRL_DISABLE,
        .source_clk = UART_SCLK_XTAL,
    };

    // Install UART driver and set pins
    uart_driver_install(UART_NUM, BUF_SIZE * 2, BUF_SIZE * 2, 20, &uart_queue, 0);
    uart_param_config(UART_NUM, &uart_config);
    uart_set_pin(UART_NUM, UART_TX_PIN, UART_RX_PIN, UART_PIN_NO_CHANGE, UART_PIN_NO_CHANGE);

    ESP_LOGI(TAG, "UART initialized successfully");
}

#if DATA_SIMULATION
// Timer callback function to send DLMS data
void dlms_data_timer_callback(TimerHandle_t xTimer)
{
    // ESP_LOGI(TAG, "Sending DLMS test data...");
    uart_write_bytes(UART_NUM, (const char *)dlmsFrame, dlmsFrameSize);
    // uart_write_bytes(UART_NUM, (const char *)kamstrup_test_data, kamstrup_test_data_size);
}
#endif

static void bdb_start_top_level_commissioning_cb(uint8_t mode_mask)
{
    ESP_RETURN_ON_FALSE(esp_zb_bdb_start_top_level_commissioning(mode_mask) == ESP_OK, , TAG, "Failed to start Zigbee commissioning");
}
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
void app_main(void)
{
    const esp_app_desc_t *app_desc = esp_app_get_description();
    
    ESP_LOGI(TAG, "========================================");
    ESP_LOGI(TAG, "WattZig Started");
    ESP_LOGI(TAG, "Version: %s", app_desc->version);
    ESP_LOGI(TAG, "Build Date: %s", app_desc->date);
    ESP_LOGI(TAG, "Build Time: %s", app_desc->time);
    ESP_LOGI(TAG, "Project Name: %s", app_desc->project_name);
    ESP_LOGI(TAG, "========================================");

    esp_log_level_set("Parser", ESP_LOG_NONE);

    gpio_reset_pin(LED_PIN);
    gpio_set_direction(LED_PIN, GPIO_MODE_OUTPUT);
    gpio_reset_pin(LED_PIN2);
    gpio_set_direction(LED_PIN2, GPIO_MODE_OUTPUT);
    gpio_set_level(LED_PIN, 0);
    gpio_set_level(LED_PIN2, 0);

    button_config_t gpio_btn_cfg = {
        .type = BUTTON_TYPE_GPIO,
        .long_press_time = 4000,
        .short_press_time = CONFIG_BUTTON_SHORT_PRESS_TIME_MS,
        .gpio_button_config = {
            .gpio_num = 4,
            .active_level = 1,
        },
    };
    button_handle_t gpio_btn = iot_button_create(&gpio_btn_cfg);
    if (NULL == gpio_btn)
    {
        ESP_LOGE(TAG, "Button create failed");
    }

    iot_button_register_cb(gpio_btn, BUTTON_LONG_PRESS_START, button_long_press_cb, NULL);
    iot_button_register_cb(gpio_btn, BUTTON_DOUBLE_CLICK, button_press_cb, NULL);

    // //-------------ADC1 Init---------------//
    // adc_oneshot_unit_handle_t adc1_handle;
    // adc_oneshot_unit_init_cfg_t init_config1 = {
    //     .unit_id = ADC_UNIT_1,
    // };
    // ESP_ERROR_CHECK(adc_oneshot_new_unit(&init_config1, &adc1_handle));

    // //-------------ADC1 Config---------------//
    // adc_oneshot_chan_cfg_t adcConfig = {
    //     .atten = ADC_ATTEN_DB_12,
    //     .bitwidth = ADC_BITWIDTH_DEFAULT,
    // };

    // ESP_ERROR_CHECK(adc_oneshot_config_channel(adc1_handle, ADC_CHANNEL_3, &adcConfig));

    // adc_cali_handle_t handle = NULL;
    // ESP_LOGI(TAG, "calibration scheme version is %s", "Curve Fitting");
    // adc_cali_curve_fitting_config_t cali_config = {
    //     .unit_id = ADC_UNIT_1,
    //     .atten = ADC_ATTEN_DB_12,
    //     .bitwidth = ADC_BITWIDTH_DEFAULT,
    // };
    // ESP_ERROR_CHECK(adc_cali_create_scheme_curve_fitting(&cali_config, &handle));

    // bool power_on = false;

    // while (!power_on)
    // {
    //     ESP_ERROR_CHECK(adc_oneshot_read(adc1_handle, ADC_CHANNEL_3, &adc_raw[0][0]));
    //     ESP_LOGI(TAG, "ADC%d Channel[%d] Raw Data: %d", ADC_UNIT_1 + 1, ADC_CHANNEL_3, adc_raw[0][0]);

    //     ESP_ERROR_CHECK(adc_cali_raw_to_voltage(handle, adc_raw[0][0], &voltage[0][0]));
    //     ESP_LOGI(TAG, "ADC%d Channel[%d] Cali Voltage: %d mV", ADC_UNIT_1 + 1, ADC_CHANNEL_3, voltage[0][0]);

    //     if (voltage[0][0] > 1600)
    //     {
    //         power_on = true;

    //         gpio_set_level(LED_PIN, 1);
    //         vTaskDelay(1000 / portTICK_PERIOD_MS);
    //         gpio_set_level(LED_PIN, 0);

    //         ESP_LOGI(TAG, "Power detected - starting application");
    //         vTaskDelay(pdMS_TO_TICKS(10000));
    //         ESP_LOGI(TAG, "Power detected - started");

    //         gpio_set_level(LED_PIN2, 1);
    //         vTaskDelay(2000 / portTICK_PERIOD_MS);
    //         gpio_set_level(LED_PIN2, 0);
    //     }
    //     else
    //     {
    //         ESP_LOGI(TAG, "No power detected - waiting...");
    //         vTaskDelay(pdMS_TO_TICKS(1000));
    //     }
    // }

    // adc_digi_stop(void);

    // Initialize UART
    uart_init();

    // Initialize DLMS parser
    dlms_parser_init(&parser);
    dlms_parser_set_callback(&parser, handle_dlms_field);

#if DATA_SIMULATION
    simulateData();
#endif

    esp_zb_platform_config_t config = {
        .radio_config = ESP_ZB_DEFAULT_RADIO_CONFIG(),
        .host_config = ESP_ZB_DEFAULT_HOST_CONFIG(),
    };
    ESP_ERROR_CHECK(nvs_flash_init());
    ESP_ERROR_CHECK(esp_zb_power_save_init());
    ESP_ERROR_CHECK(esp_zb_platform_config(&config));

    gpio_set_level(LED_PIN, 1);
    vTaskDelay(1000 / portTICK_PERIOD_MS);
    gpio_set_level(LED_PIN, 0);

    ESP_LOGI(TAG, "Power detected - starting application");
    vTaskDelay(pdMS_TO_TICKS(10000));
    ESP_LOGI(TAG, "Power detected - started");

    gpio_set_level(LED_PIN2, 1);
    vTaskDelay(2000 / portTICK_PERIOD_MS);
    gpio_set_level(LED_PIN2, 0);

    xTaskCreate(esp_zb_task, "Zigbee_main", 4096, NULL, 5, NULL);
}

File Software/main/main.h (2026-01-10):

#include "esp_zigbee_core.h"

/* Zigbee configuration */
#define INSTALLCODE_POLICY_ENABLE false /* enable the install code policy for security */
#define ENDPOINT_ID 10
#define ESP_ZB_PRIMARY_CHANNEL_MASK ESP_ZB_TRANSCEIVER_ALL_CHANNELS_MASK /* Zigbee primary channel mask use in the example */

#define ED_AGING_TIMEOUT ESP_ZB_ED_AGING_TIMEOUT_64MIN
#define ED_KEEP_ALIVE 3000 /* 3000 millisecond */

#define MANUFACTURER_NAME "\x10" \
                          "Peer Bech Hansen"
#define MODEL_IDENTIFIER "\x07" \
                         "WattZig"

// UART configuration
#define UART_NUM UART_NUM_1 // Use UART1

#define UART_TX_PIN 0 // TX pin (adjust as needed)
#define UART_RX_PIN 1 // RX pin (adjust as needed)

#define UART_BAUD_RATE 2400 // Baud rate
#define BUF_SIZE 1024       // Buffer size
#define UART_RX_BUFFER_SIZE 1024
#define UART_QUEUE_SIZE 10

#define LED_PIN 5
#define LED_PIN2 6

#define DATA_SIMULATION false

#define ESP_ZB_ZED_CONFIG()                               \
    {                                                     \
        .esp_zb_role = ESP_ZB_DEVICE_TYPE_ED,             \
        .install_code_policy = INSTALLCODE_POLICY_ENABLE, \
        .nwk_cfg.zed_cfg = {                              \
            .ed_timeout = ED_AGING_TIMEOUT,               \
            .keep_alive = ED_KEEP_ALIVE,                  \
        },                                                \
    }

#define ESP_ZB_DEFAULT_RADIO_CONFIG()       \
    {                                       \
        .radio_mode = ZB_RADIO_MODE_NATIVE, \
    }

#define ESP_ZB_DEFAULT_HOST_CONFIG()                          \
    {                                                         \
        .host_connection_mode = ZB_HOST_CONNECTION_MODE_NONE, \
    }

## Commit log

2026-01-08 Initial public release
    [PowerMeter.kicad_pcb, PowerMeter.kicad_sch, partitions.csv]
2026-01-10 Rename project from PowerMeter to WattZig and update related documentation and configurations
2026-02-28 Added voltage measurement for 4.1 volt
    [PowerMeter.kicad_pcb, PowerMeter.kicad_sch]
